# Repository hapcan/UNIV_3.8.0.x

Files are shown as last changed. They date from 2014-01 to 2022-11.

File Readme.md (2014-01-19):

UNIV 3.8.0.x
============

RGB LED Controller - 3 channel LED or 1 channel RGB LED controller 5A per channel @12-24V for DIN rail

Device webpage: http://hapcan.com/devices/universal/univ_3/univ_3-8-0-x/

Hardware created in Eagle PCB Software http://www.cadsoftusa.com/

Firmware created in Microchip MPLAB http://www.microchip.com/mplabide/ in assembly language

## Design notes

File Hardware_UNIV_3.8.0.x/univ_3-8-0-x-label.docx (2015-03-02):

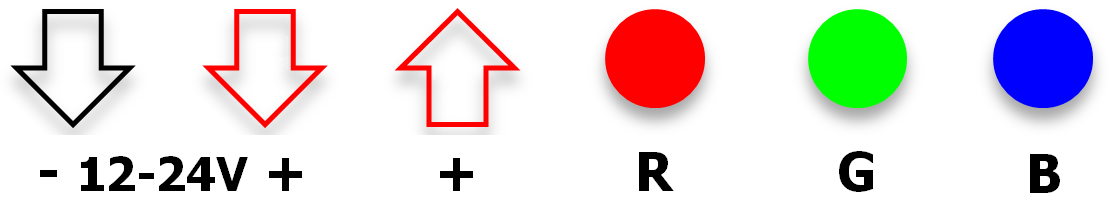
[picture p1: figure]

RGB LED

CONTROLLER

IN = 3x5A UN = 12-24V
TYPE | UNIV 3.8.0.x
S/N | 000005D8h

hapcan.com

STEROWNIK

RGB LED

IN = 3x5A UN = 12-24V
TYP | UNIV 3.8.0.x
S/N | 000005D8h

hapcan.com

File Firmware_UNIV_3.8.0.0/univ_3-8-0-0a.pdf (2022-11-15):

# RGB LED CONTROLLER FIRMWARE

# UNIV 3.8.0.0

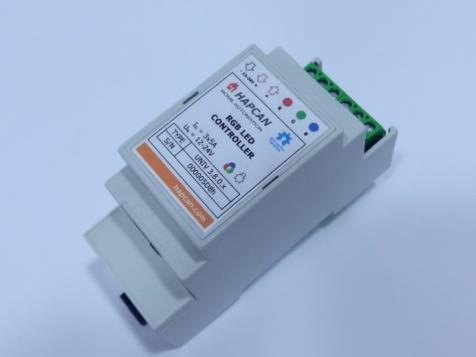
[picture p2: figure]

© 2014 hapcan.com | univ_3-8-0-0a.pdf - page 1 / 6

## 1. Features

- Firmware for RGB LED controller - Voltage control (PWM) in 255 steps (0-255) for each channel - MASTER channel adjustable in 255 steps as well - Possibility to set up minimum and maximum value for each channel - Last state memory - Adjustable dimming time for each channel - 37 control instructions - 3 blocking instructions - 4 timers (1 for each channel) for instruction execution delay 1s-24h - Allows defining up to 128 CAN messages which can indirectly control the module - Settable power up states - Uptime counter - Health check monitor - Transmit (42 messages) and receive (42 messages) FIFO buffers

## 2. Compatibility - Firmware for UNIV 3.8.0.x module - Firmware can be uploaded into processor with bootloader version 3.1 or

compatible.

## 3. Firmware version

UNIV | 3 | . | 8 | . | 0 | . | 0

## firmware version application version application type (RGB LED controller) processor version universal processor

## 4. Communication Frames (messages)

## 4.1. RGB LED controller message

The module sends message to the bus, when the status of any channel changes.

## Table 1. RGB LED controller frame (0x308)

Frame type | Flags | Module | Group | D0 | D1 | D2 | D3 | D4 | D5 | D6 | D7
0x308 | 3 | 2 | 1 | 0 | Node Nr | Group Nr | 0xFF | 0xFF | CHANNEL | STATUS | RELAY | INSTR1 | INSTR2 | TIMER
0x308 | – universal module frame, RGB LED controller
3 | - | - not used flag, read as “0”
2 | - | - not used flag, read as “0”
1 | - | - not used flag, read as “0”
0 | RE | - response flag, flag is equal “1” if node was requested. If flag is equal „0” it means that status of output has just changed.
Node Nr | - message sender node number
Group Nr | - message sender group number
CHANNEL | - output channel (0x01 – red, 0x02 – green, 0x03 – blue, 0x04 - MASTER)
STATUS | - current status of output 0x00 – 0xFF
PRZEK | - current status of all channels (0x00 – if all channels are turned off, 0xFF – if master
| | channel and any colour channe is on) – this byte can be used to toggle relay which
| | turns on the power supply for the LED. This byte is only available in MASTER channel frame
INSTR1 | - instruction that is waiting for execution, or 0xFF if none instruction
INSTR2 | - second byte of instruction that is waiting for execution, or 0xFF
TIMER | - delay value of waiting instruction, or 0x00 if none waiting

# UNIV 3.8.0.0

## 4.2. Status request

Status of module can be checked by sending from computer STATUS REQUEST frame (0x109) (Table 2).

Table 2. STATUS REQUEST frame (0x109).
Frame type | Flags | Module | Group | D0 | D1 | D2 | D3 | D4 | D5 | D6 | D7
0x109 | 0x0 | COMP ID1 | COMP ID2 | 0xXX | 0xXX | Node Nr | Group Nr | 0xXX | 0xXX | 0xXX | 0xXX
0x1090 | – STATUS REQUEST frame
COMP ID1 | - computer identifier (must be unique on the network)
COMP ID2 | - computer identifier (must be unique on the network)
Node Nr | - node number of requested module
Group Nr | - group number of requested module
0xXX | - inessential data

As response the module will send RGB LED frames. The meaning of bytes is the same as in Table 1.

## Table 3. Response to STATUS REQUEST

Frame type | Flags | Module | Group | D0 | D1 | D2 | D3 | D4 | D5 | D6 | D7
0x308 | 0x1 | Node Nr | Group Nr | 0xFF | 0xFF | 0x01 | STATUS | 0xFF | INSTR1 | INSTR2 | TIMER1
Frame type | Flags | Module | Group | D0 | D1 | D2 | D3 | D4 | D5 | D6 | D7
0x308 | 0x1 | Node Nr | Group Nr | 0xFF | 0xFF | 0x02 | STATUS | 0xFF | INSTR1 | INSTR2 | TIMER2
Frame type | Flags | Module | Group | D0 | D1 | D2 | D3 | D4 | D5 | D6 | D7
0x308 | 0x1 | Node Nr | Group Nr | 0xFF | 0xFF | 0x03 | STATUS | 0xFF | INSTR1 | INSTR2 | TIMER3
Frame type | Flags | Module | Group | D0 | D1 | D2 | D3 | D4 | D5 | D6 | D7
0x308 | 0x1 | Node Nr | Group Nr | 0xFF | 0xFF | 0x04 | STATUS | RELAY | INSTR1 | INSTR2 | TIMER4

## 4.3. Uptime request

Table 4. UPTIME REQUEST (0x113).
Frame type | Flags | Module | Group | D0 | D1 | D2 | D3 | D4 | D5 | D6 | D7
0x113 | 0x0 | COMP ID1 | COMP ID2 | 0xXX | 0xXX | Node Nr | Group Nr | 0xXX | 0xXX | 0xXX | 0xXX
0x1130 | – UPTIME REQUEST frame
COMP ID1 | - computer identifier (must be unique on the network)
COMP ID2 | - computer identifier (must be unique on the network)
Node Nr | - node number of requested module
Group Nr | - group number of requested module
0xXX | - inessential data

Table 5. Response to UPTIME REQUEST (0x113).
Frame type | Flags | Module | Group | D0 | D1 | D2 | D3 | D4 | D5 | D6 | D7
0x113 | 0x1 | Node Nr | Group Nr | 0xFF | 0xFF | 0xFF | 0xFF | UPTIME3 | UPTIME2 | UPTIME1 | UPTIME0
0x1131 | – Response to UPTIME REQUEST frame
Node Nr | - node number on the network
Group Nr | - group number of the node on the network
UPTIME | - (UPTIME3*256³+UPTIME2*256²+UPTIME1*256¹+UPTIME3*256⁰

### ) in seconds

## 4.4. Health check request

Table 6. HEALTH CHECK - STATUS REQUEST (0x115).
Frame type | Flags | Module | Group | D0 | D1 | D2 | D3 | D4 | D5 | D6 | D7
0x115 | 0x0 | COMP ID1 | COMP ID2 | 0x01 | 0xXX | Node Nr | Group Nr | 0xXX | 0xXX | 0xXX | 0xXX
0x1150 | – HEALTH CHECK REQUEST frame
COMP ID1 | - computer identifier (must be unique on the network)
COMP ID2 | - computer identifier (must be unique on the network)
0x01 | - status request
Node Nr | - node number of requested module
Group Nr | - group number of requested module
0xXX | - inessential data

As response the module will send two frames (Table 7).

Table 7. Response to HEALTH CHECK - STATUS REQUEST (0x115).
Frame type | Flags | Module | Group | D0 | D1 | D2 | D3 | D4 | D5 | D6 | D7
0x115 | 0x1 | Node Nr | Group Nr | 0x01 | RXCNT | TXCNT | RXCNTMX | TXCNTMX | CANINTCNT | RXERRCNT | TXERRCNT
0x1151 | – Response to HEALTH CHECK REQUEST frame
Node Nr | - node number on the network
Group Nr | - group number of the node on the network
0x01 | - frame 1 (current values)
RXCNT | - current level of receive FIFO buffer
TXCNT | - current level of transmit FIFO buffer
RXCNTMX | - maximum level of receive FIFO buffer since power up
TXCNTMX | - maximum level of transmit FIFO buffer since power up
CANINTCNT | - number of CAN interface restarts since power up
RXERRCNT | - current receive errors register
TXERRCNT | - current transmit errors register
Frame type | Flags | Module | Group | D0 | D1 | D2 | D3 | D4 | D5 | D6 | D7
0x115 | 0x1 | Node Nr | Group Nr | 0x02 | 0xFF | 0xFF | RXCNTMXE | TXCNTMXE | CANINTCNTE | RXERRCNTE | TXERRCNTE
0x1151 | – Response to HEALTH CHECK REQUEST frame
Node Nr | - node number on the network
Group Nr | - group number of the node on the network
0x02 | - frame 2 (maximum values saved in eeprom memory)
RXCNTMXE | - maximum ever level of receive FIFO buffer
TXCNTMXE | - maximum ever level of transmit FIFO buffer
CANINTCNTE | - maximum ever number of CAN interface restarts
RXERRCNTE | - maximum ever receive errors
TXERRCNTE | - maximum ever transmit errors

To clear maximum values saved in eeprom memory the frame shown in Table 8 must be sent. There is no response to this message.

Table 8. HEALTH CHECK - CLEAR REQUEST (0x115).
Frame type | Flags | Module | Group | D0 | D1 | D2 | D3 | D4 | D5 | D6 | D7
0x115 | 0x0 | COMP ID1 | COMP ID2 | 0x02 | 0xXX | Node Nr | Group Nr | 0xXX | 0xXX | 0xXX | 0xXX
0x1150 | – HEALTH CHECK REQUEST frame
COMP ID1 | - computer identifier (must be unique on the network)
COMP ID2 | - computer identifier (must be unique on the network)
0x02 | - clear request
Node Nr | - node number of requested module
Group Nr | - group number of requested module
0xXX | - inessential data

## 5. Module control

The module can be controlled directly from PC, or indirectly by other modules.

## 5.1. Control instruction

The table below shows all instructions, which can be executed by the module. Some of them can be executed only with direct control and other with indirect control (through other modules).

## Table 9. Module control instructions

Instrukcja | Instruction Codding | Note | Control
INSTR1 | INSTR2 | INSTR3 | INSTR4 | INSTR5 | INSTR6 | INSTR7 | INSTR8
SET LED1 (R) TO… | 0x00 | STATE | TIMER | 0xXX | 0xXX | 0xXX | 0xXX | 0xXX | Sets the state of the channel immediately at the level specified by the byte STATE (0-255). Instructions may be delayed if the TIMER is not zero. | √ | √
SET LED2 (G) TO… | 0x01 | STATE | TIMER | 0xXX | 0xXX | 0xXX | 0xXX | 0xXX
SET LED3 (B) TO… | 0x02 | STATE | TIMER | 0xXX | 0xXX | 0xXX | 0xXX | 0xXX
SET MASTER TO… | 0x03 | STATE | TIMER | 0xXX | 0xXX | 0xXX | 0xXX | 0xXX
TOGGLE LED1 | 0x04 | 0xXX | TIMER | 0xXX | 0xXX | 0xXX | 0xXX | 0xXX | If the channel is on, it will be turned off. If it is off, it will be turned to the maximum or the last memorized value (if state memory is set in the configuration). Instructions may be delayed if the TIMER is not zero. | √ | √
TOGGLE LED2 | 0x05 | 0xXX | TIMER | 0xXX | 0xXX | 0xXX | 0xXX | 0xXX
TOGGLE LED3 | 0x06 | 0xXX | TIMER | 0xXX | 0xXX | 0xXX | 0xXX | 0xXX
TOGGLE MASTER | 0x07 | 0xXX | TIMER | 0xXX | 0xXX | 0xXX | 0xXX | 0xXX
STEP DOWN LED1 BY … | 0x08 | VALUE | TIMER | 0xXX | 0xXX | 0xXX | 0xXX | 0xXX | Channel state will be reduced by the value indicated in the VALUE byte. | √ | √
STEP DOWN LED2 BY … | 0x09 | VALUE | TIMER | 0xXX | 0xXX | 0xXX | 0xXX | 0xXX
STEP DOWN LED3 BY … | 0x0A | VALUE | TIMER | 0xXX | 0xXX | 0xXX | 0xXX | 0xXX
STEP DOWN MASTER BY … | 0x0B | VALUE | TIMER | 0xXX | 0xXX | 0xXX | 0xXX | 0xXX
STEP UP LED1 BY … | 0x0C | VALUE | TIMER | 0xXX | 0xXX | 0xXX | 0xXX | 0xXX | Channel state will be increased by the value indicated in the VALUE byte. | √ | √
STEP UP LED2 BY … | 0x0D | VALUE | TIMER | 0xXX | 0xXX | 0xXX | 0xXX | 0xXX
STEP UP LED3 BY … | 0x0E | VALUE | TIMER | 0xXX | 0xXX | 0xXX | 0xXX | 0xXX
STEP UP MASTER BY … | 0x0F | VALUE | TIMER | 0xXX | 0xXX | 0xXX | 0xXX | 0xXX
SET LED1 (R) SOFTLY TO… | 0x10 | STATE | TIMER | 0xXX | 0xXX | 0xXX | 0xXX | 0xXX | Sets the state of the channel slowly to the level specified by the byte STATE (0-255). Instructions may be delayed if the TIMER is not zero. | √ | √
SET LED2 (G) SOFTLY TO… | 0x11 | STATE | TIMER | 0xXX | 0xXX | 0xXX | 0xXX | 0xXX
SET LED3 (B) SOFTLY TO… | 0x12 | STATE | TIMER | 0xXX | 0xXX | 0xXX | 0xXX | 0xXX
SET MASTER SOFTLY TO… | 0x13 | STATE | TIMER | 0xXX | 0xXX | 0xXX | 0xXX | 0xXX
STOP LED1 | 0x14 | 0xXX | 0xXX | 0xXX | 0xXX | 0xXX | 0xXX | 0xXX | It stops instruction which is being executed eg. START or SET SOFTLY TO ... | √ | √
STOP LED2 | 0x15 | 0xXX | 0xXX | 0xXX | 0xXX | 0xXX | 0xXX | 0xXX
STOP LED3 | 0x16 | 0xXX | 0xXX | 0xXX | 0xXX | 0xXX | 0xXX | 0xXX
STOP MASTER | 0x17 | 0xXX | 0xXX | 0xXX | 0xXX | 0xXX | 0xXX | 0xXX
START LED1 | 0x18 | 0xXX | 0xXX | 0xXX | 0xXX | 0xXX | 0xXX | 0xXX | Instruction START begins typical control process. If within 400ms from START instruction, controller receives STOP instruction then it toggles channel’s state (exactly the same as TOGGLE instruction). If after that time instruction STOP is not received then channel is brightened (if previous state was min or 0), or channel is dimmed (if previous state was max). It gives possibility to control with one button. If button is pressed for less than 400ms the channel will turn on or off. If button is pressed for longer than 400ms, then channel will dim or brighten. | √ | √
START LED2 | 0x19 | 0xXX | 0xXX | 0xXX | 0xXX | 0xXX | 0xXX | 0xXX
START LED3 | 0x1A | 0xXX | 0xXX | 0xXX | 0xXX | 0xXX | 0xXX | 0xXX
START MASTER | 0x1B | 0xXX | 0xXX | 0xXX | 0xXX | 0xXX | 0xXX | 0xXX
SET LED1 SPEED TO … | 0x1C | VALUE | 0xXX | 0xXX | 0xXX | 0xXX | 0xXX | 0xXX | It sets dimming time of particular channel. VALUE byte (0-255) defines time when channel changes its state from 0 to 255. This byte can hold value from 0 – 255 which corresponds to 1s – 256s. | √ | √
SET LED2 SPEED TO … | 0x1D | VALUE | 0xXX | 0xXX | 0xXX | 0xXX | 0xXX | 0xXX
SET LED3 SPEED TO … | 0x1E | VALUE | 0xXX | 0xXX | 0xXX | 0xXX | 0xXX | 0xXX
SET MASTER SPEED TO … | 0x1F | VALUE | 0xXX | 0xXX | 0xXX | 0xXX | 0xXX | 0xXX
SET RGB TO… | 0x20 | STATE1 | STATE2 | STATE3 | TIMER | 0xXX | 0xXX | 0xXX | It sets immediately values of three colour channels. Instruction may be delayed if the TIMER is not zero. | √ | √
SET SOFTLY RGB TO… | 0x21 | STATE1 | STATE2 | STATE3 | TIMER | 0xXX | 0xXX | 0xXX | It sets slowly values of three colour channels. Instruction may be delayed if the TIMER is not zero. | √ | √
SET RGB SPEED TO… | 0x22 | VALUE | 0xXX | 0xXX | 0xXX | 0xXX | 0xXX | 0xXX | It sets dimming time of three colour channels. VALUE byte (0-255) defines time when channel changes its state from 0 to 255. This byte can hold value from 0 – 255 which corresponds to 1s – 256s. | √ | √
RGB SPEED UP | 0x23 | 0xXX | 0xXX | 0xXX | 0xXX | 0xXX | 0xXX | 0xXX | It changes dimming speed of three colour channels to next lower value | √ | √
RGB SPEED DOWN | 0x24 | 0xXX | 0xXX | 0xXX | 0xXX | 0xXX | 0xXX | 0xXX | It changes dimming speed of three colour channels to next higher value | √ | √
PROGRAM | 0x25 | 0x00 | 0xXX | 0xXX | 0xXX | 0xXX | 0xXX | 0xXX | It stops any running program. | √ | √
| | 0x01 | 0xXX | 0xXX | 0xXX | 0xXX | 0xXX | 0xXX | Program 1 – every program calling causes colour changing with sequence: 1-red 2-green 3-blue 4-yellow 5-cyan 6-violet 7-white
| | 0x02 | 0xXX | 0xXX | 0xXX | 0xXX | 0xXX | 0xXX | Program 2 – first program calling runs automatic colour changing with current dimming speed beginning from red colour. The second program calling stops colour. Another calling starts colour changing with reversed order.
ENABLE BOX | 0xDD | BoxX | BoxY | 0xXX | 0xXX | 0xXX | 0xXX | 0xXX | It enables chosen boxes – these boxes will be compared with next received message from the bus. | | √
DISABLE BOX | 0xDE | BoxX | BoxY | 0xXX | 0xXX | 0xXX | 0xXX | 0xXX | It disables chosen boxes – these boxes will be passed when next message arrives from the bus. | | √
TOGGLE BOX | 0xDF | BoxX | BoxY | 0xXX | 0xXX | 0xXX | 0xXX | 0xXX | It toggles boxes – enables when they are disabled and vice versa | | √

Direct

Indirect

0xXX – inessential data

BoxX | Note
0x00 | - from Box 1
0x01 | - from Box 2
…
0x7F | - from Box 128
BoxY | Note
0x00 | + 0 -(and not anyone else)
0x01 | + 1 -( and 1 following)
…
0x7F | +127 -( and 127 following)

## 5.2. Timer

Each channel has its own timer which can delay execution of the instruction. Delay can be chosen between 1s-24h set in TIMER register. Drawing below shows delay dependence of TIMER register.

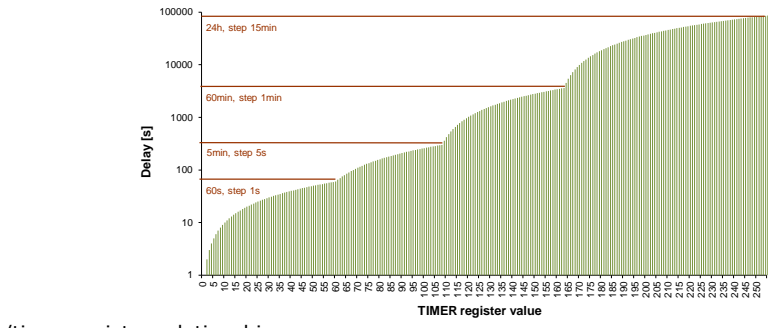
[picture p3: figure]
Delay [s]; TIMER register value; 60s, step 1s; 5min, step 5s; 60min, step 1min; 24h, step 15min

## Figure 1. Delay/timer register relationship

## 5.3. Direct control

It is possible to control module by sending DIRECT CONTROL message. The message contains instruction, which will be executed by the module.

Table 10. DIRECT CONTROL frame (0x10A).
Frame type | Flags | Module | Group | D0 | D1 | D2 | D3 | D4 | D5 | D6 | D7
0x10A | 0x0 | COMP ID1 | COMP ID2 | INSTR1 | INSTR2 | Node Nr | Group Nr | INSTR3 | INSTR4 | INSTR5 | INSTR6
0x10A | – DIRECT CONTROL frame
COMP ID1 | - computer identifier (must be unique on the network)
COMP ID2 | - computer identifier (must be unique on the network)
Node Nr | - node number of requested module
Group Nr | - group number of requested module
INSTR1-6 | - instruction to be executed (byte1)

## 5.4. Indirect control

Indirect control means that module will react to messages sent by other modules on the network. It depends on configuration programmed into the module boxes (memory cells).
This firmware has feature to set simple conditions of executing instruction. To do so, you can use blocking instruction (0xDD – 0xDF) shown in Table 9.

## 6. Configuration Parameters that can be configured with this firmware:

- Module identifier (module number and group number);
- Module description (16 chars);
- Minimum and maximum values;
- Power up dimming speed;
- Power up states;
- Last state memory;
- Text notes;
- Linking device with other modules (indirect control of module). Configuration process can be done using HAPCAN Programmer.

## 6.1. Module identifier

Every module on the network must have unique identifier. The identifier is made of two bytes, module number (1 byte) and group number (1 byte). Identifier of the Ethernet Interface can be changed in HAPCAN Programmer in software settings.

## 6.2. Module description

Every module can have 16 char description, which makes easier for user (programmer) to distinguish nodes.

## 6.3. Minimum and maximum values

It is possible to set minimum and maximum values for each channel.

## 6.4. Power up dimming speed

This parameter defines how fast channel goes from value 0 to value 255. The dimming speed can be chosen between 1s and 256s with 1s step.

## 6.5. Power up states

It is possible to configure channel states at startup after power loss. At startup values can be chosen between 0 and 255 or the or the last state saved in non-volatile memory can be taken. The last state value must be unchanged for at least 6s before power failure.

## 6.6. Last state memory

The last state of any channel can be remembered. In this mode, when channel is being switched on, it sets to the value that was before switching off. In no state memory mode it sets to the maximum value.

6.7. Text notes.
Up to 1024 characters can be written into processor’s memory.

## 6.8. Linking devices

The module has 128 memory cells (boxes). Each box can contain information about message sent by other node, and instruction which will be executed when that message is received.

## 7. License

## HAPCAN Home Automation Project firmware, Copyright (C) 2014 hapcan.com

This program is free firmware: you can redistribute it and/or modify it under the terms of the GNU General Public License as published by the Free Software Foundation, either version 3 of the License, or (at your option) any later version.

This firmware is distributed in the hope that it will be useful, but WITHOUT ANY WARRANTY; without

## even the implied warranty of MERCHANTABILITY or FITNESS FOR A PARTICULAR PURPOSE. See the

GNU General Public License for more details.

You should have received a copy of the GNU General Public License along with this firmware. If not, see http://www.gnu.org/licenses/gpl-3.0.html.

## 8. Document version

File | Note | Date
univ_3-8-0-0a.pdf | Original version | January 2014

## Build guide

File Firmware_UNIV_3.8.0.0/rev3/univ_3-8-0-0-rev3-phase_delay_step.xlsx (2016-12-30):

TIME reg | number of 20ms interrupts | number of steps on each 20ms | calculated PHASE step value (HEX) |  |  | final real PHASE delay
0 | 50 | 5.1 | 51999 | 334233 | 5.100068666 | 0.9999865363
1 | 100 | 2.55 | 28CCC | 167116 | 2.550026703 | 1.999979056
2 | 150 | 1.7 | 1B333 | 111411 | 1.700022889 | 2.999959609
3 | 200 | 1.275 | 14666 | 83558 | 1.275013352 | 3.999958113
4 | 250 | 1.02 | 1051E | 66846 | 1.020004578 | 4.99997756
5 | 300 | 0.85 | D999 | 55705 | 0.8500038148 | 5.999973072
6 | 350 | 0.7285714286 | BA83 | 47747 | 0.7285725185 | 6.999989528
7 | 400 | 0.6375 | A333 | 41779 | 0.6375066758 | 7.999916226
8 | 450 | 0.5666666667 | 9111 | 37137 | 0.5666742962 | 8.999878827
9 | 500 | 0.51 | 828F | 33423 | 0.5100022889 | 9.999955121
10 | 550 | 0.4636363636 | 76B0 | 30384 | 0.4636301213 | 11.0001481
11 | 600 | 0.425 | 6CCC | 27852 | 0.4249942779 | 12.00016157
12 | 650 | 0.3923076923 | 646E | 25710 | 0.392309453 | 12.99994166
13 | 700 | 0.3642857143 | 5D41 | 23873 | 0.3642786297 | 14.00027227
14 | 750 | 0.34 | 570A | 22282 | 0.3400015259 | 14.99993268
15 | 800 | 0.31875 | 5199 | 20889 | 0.3187457084 | 16.00021542
16 | 850 | 0.3 | 4CCC | 19660 | 0.2999923705 | 17.00043235
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

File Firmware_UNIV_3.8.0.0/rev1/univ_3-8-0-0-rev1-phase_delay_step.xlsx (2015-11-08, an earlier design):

TIME reg | number of 20ms interrupts | number of stapes on each 20ms | calculated PHASE step value (HEX) |  |  | final real PHASE delay
0 | 50 | 5.1 | 51999 | 334233 | 5.100068666 | 0.9999865363
1 | 100 | 2.55 | 28CCC | 167116 | 2.550026703 | 1.999979056
2 | 150 | 1.7 | 1B333 | 111411 | 1.700022889 | 2.999959609
3 | 200 | 1.275 | 14666 | 83558 | 1.275013352 | 3.999958113
4 | 250 | 1.02 | 1051E | 66846 | 1.020004578 | 4.99997756
5 | 300 | 0.85 | D999 | 55705 | 0.8500038148 | 5.999973072
6 | 350 | 0.7285714286 | BA83 | 47747 | 0.7285725185 | 6.999989528
7 | 400 | 0.6375 | A333 | 41779 | 0.6375066758 | 7.999916226
8 | 450 | 0.5666666667 | 9111 | 37137 | 0.5666742962 | 8.999878827
9 | 500 | 0.51 | 828F | 33423 | 0.5100022889 | 9.999955121
10 | 550 | 0.4636363636 | 76B0 | 30384 | 0.4636301213 | 11.0001481
11 | 600 | 0.425 | 6CCC | 27852 | 0.4249942779 | 12.00016157
12 | 650 | 0.3923076923 | 646E | 25710 | 0.392309453 | 12.99994166
13 | 700 | 0.3642857143 | 5D41 | 23873 | 0.3642786297 | 14.00027227
14 | 750 | 0.34 | 570A | 22282 | 0.3400015259 | 14.99993268
15 | 800 | 0.31875 | 5199 | 20889 | 0.3187457084 | 16.00021542
16 | 850 | 0.3 | 4CCC | 19660 | 0.2999923705 | 17.00043235
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

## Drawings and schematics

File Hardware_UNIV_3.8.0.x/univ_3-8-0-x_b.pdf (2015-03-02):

## RGB LED CONTROLLER

# UNIV 3.8.0.x

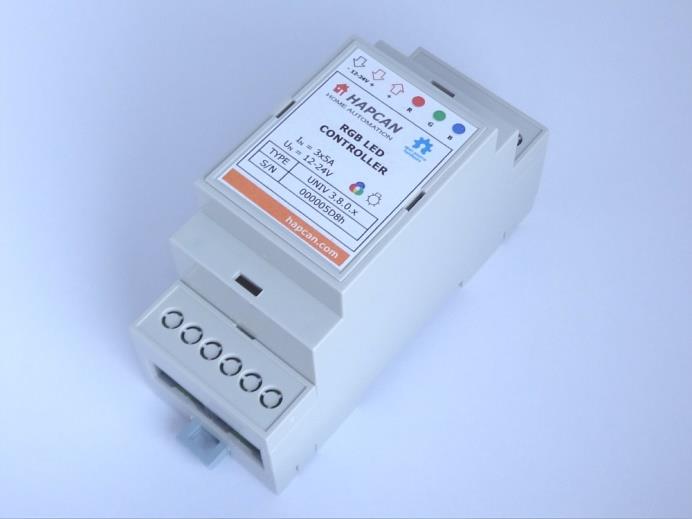
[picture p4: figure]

© 2014 hapcan.com | univ_3-8-0-x_b.pdf - page 1 / 6

### 1. Features

- 3 channel LED controller
- Maximum load 120VA for each channel
- PWM (Pulse Width Modulation)
- Controller can generate any colour with required intensity of common anode RGB LED.
- Can work with:
- - RGB LEDs or three single colour LEDs (eg. LED strips, tapes, tubes etc.)
- - low voltage bulbs (classical and halogen 12-24V)
- Maximum LED supply voltage 12-24V
- Maximum LED current 5A for each channel
- Operation voltage 10-24V.
- Maximum current consumption from the bus 26mA.
- For DIN rail mounting.
- Dimensions 90x58x36 mm (2 mod)
- Operating of module depends on firmware uploaded into it.
- Schematic and PCB design can be downloaded from hapcan.com site

### 2. Application version

UNIV | 3 | . | 8 | . | 0 | . | x
firmware version
application version
application type (RGB LED controller) processor version
universal processor

### 3. Technical data

Bus side
Parameter | Symbol | Value | Unit
Power supply voltage | US | 10-24V | V
Maximum current consumption with all channels turn on | ISMAX | 26 | mA
Bus quiescent current | ISQ | 7 | mA
Bus connector type | 2x RJ45 connectors

RGB LED side
Parameter | Symbol | Value | Unit
Power supply voltage | UN | 12-24V | V
Maximum LED current for one channel | IN | 5 | A
Load Power for one channel | SN | 120 | VA
Voltage regulating range | Uφ | 0 - UN | V
PWM frequency | f | 488 | Hz
Connector type | Terminal block 4mm²

## UNIV 3.8.0.x

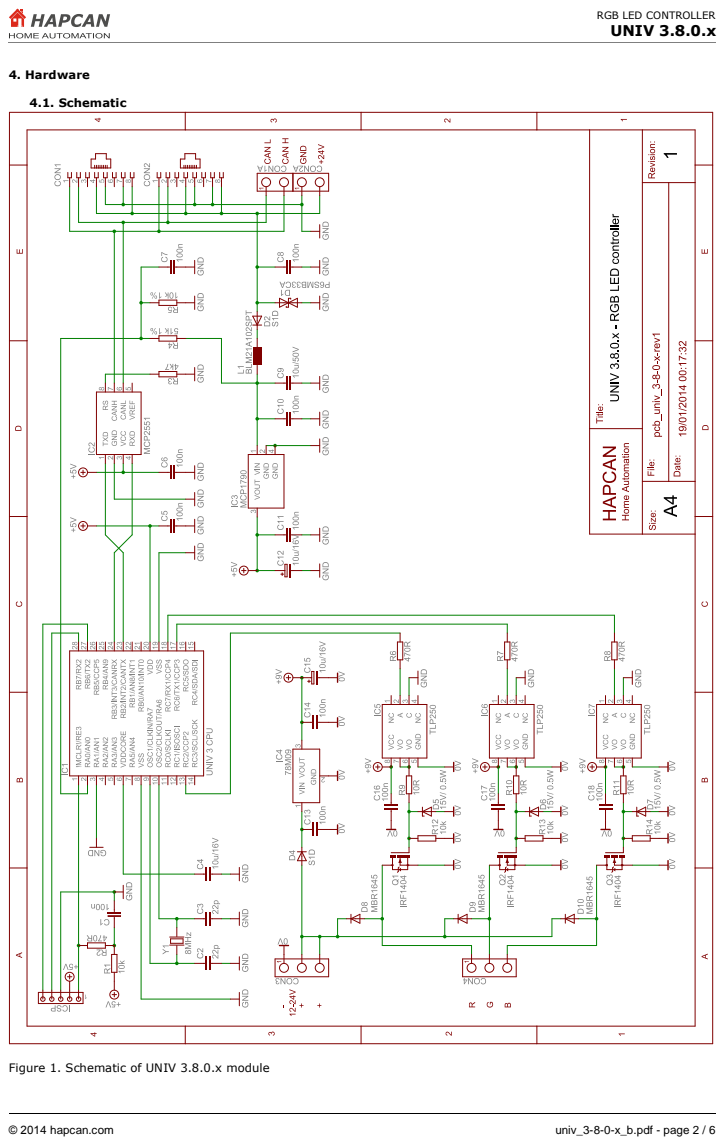
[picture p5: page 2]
4. Hardware; 4.1. Schematic

Figure 1. Schematic of UNIV 3.8.0.x module

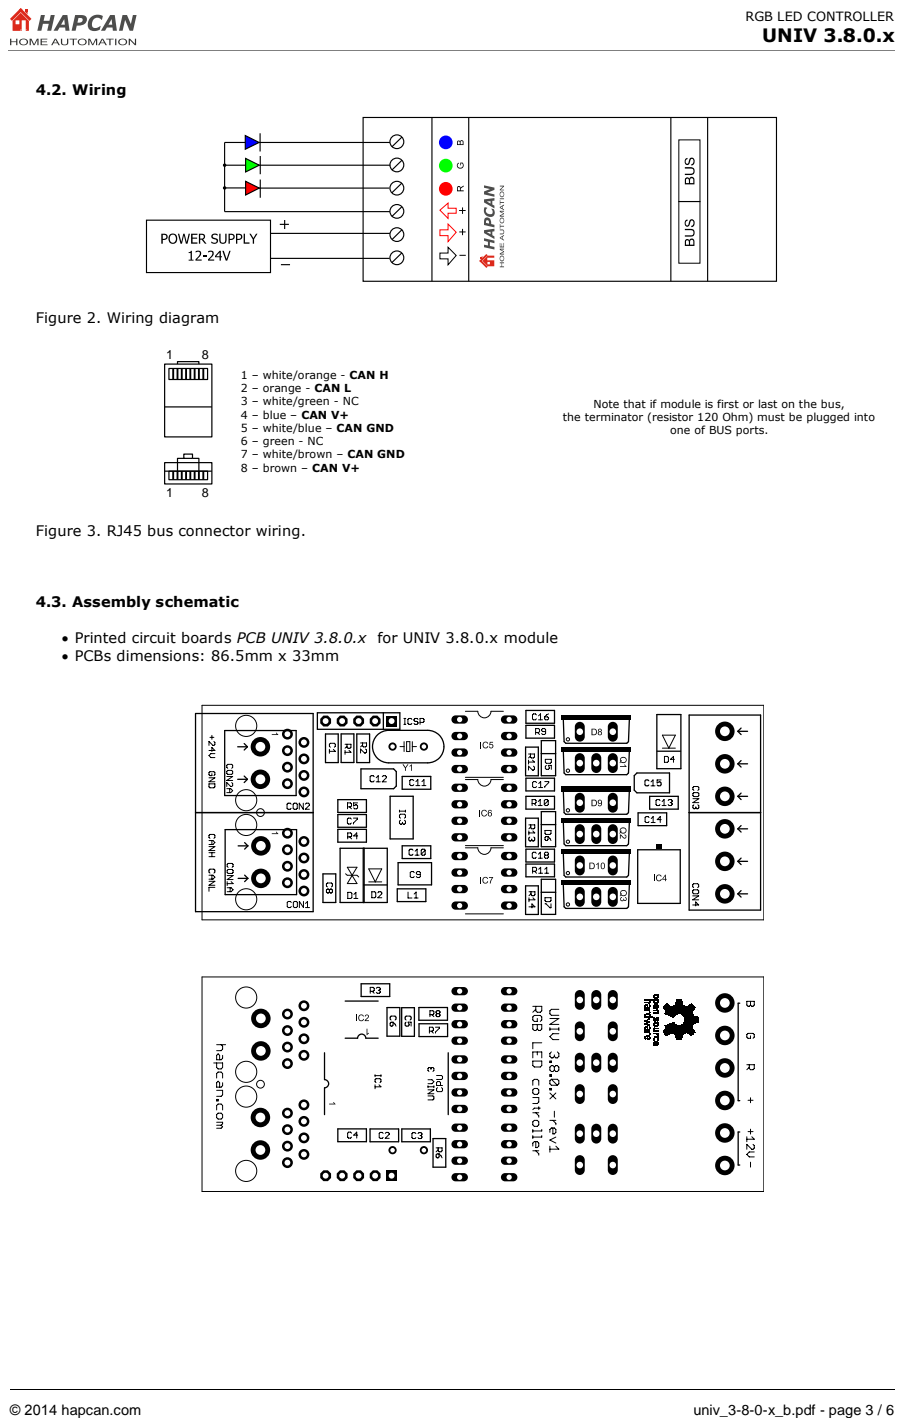
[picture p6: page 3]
4.2. Wiring; 4.3. Assembly schematic

Figure 2. Wiring diagram

1 – white/orange - CAN H
2 – orange - CAN L
3 – white/green - NC
4 – blue – CAN V+
5 – white/blue – CAN GND
6 – green - NC
7 – white/brown – CAN GND
8 – brown – CAN V+

Note that if module is first or last on the bus,
the terminator (resistor 120 Ohm) must be plugged into

one of BUS ports.

Figure 3. RJ45 bus connector wiring.

• Printed circuit boards PCB UNIV 3.8.0.x for UNIV 3.8.0.x module
• PCBs dimensions: 86.5mm x 33mm

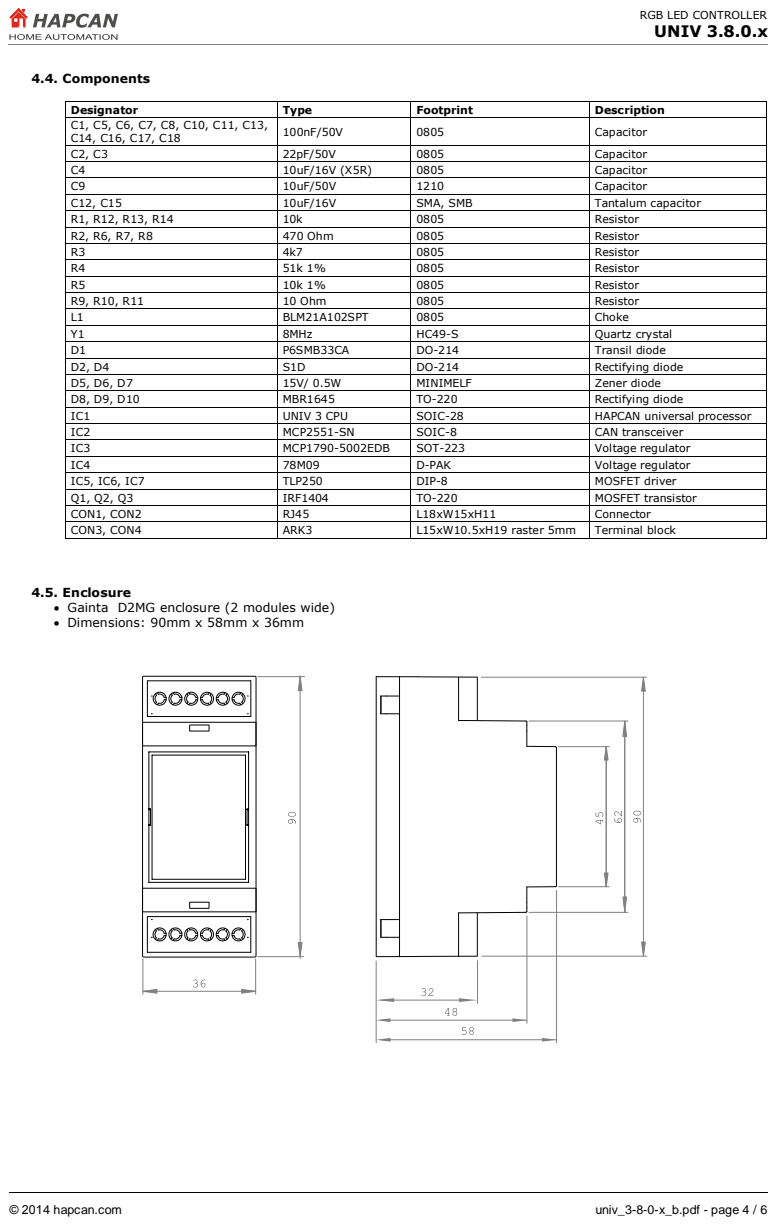
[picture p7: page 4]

Designator | Type | Footprint | Description
C1, C5, C6, C7, C8, C10, C11, C13, C14, C16, C17, C18 | 100nF/50V | 0805 | Capacitor

C2, C3 | 22pF/50V | 0805 | Capacitor
C4 | 10uF/16V (X5R) | 0805 | Capacitor
C9 | 10uF/50V | 1210 | Capacitor
C12, C15 | 10uF/16V | SMA, SMB | Tantalum capacitor
R1, R12, R13, R14 | 10k | 0805 | Resistor
R2, R6, R7, R8 | 470 Ohm | 0805 | Resistor
R3 | 4k7 | 0805 | Resistor
R4 | 51k 1% | 0805 | Resistor
R5 | 10k 1% | 0805 | Resistor
R9, R10, R11 | 10 Ohm | 0805 | Resistor
L1 | BLM21A102SPT | 0805 | Choke
Y1 | 8MHz | HC49-S | Quartz crystal
D1 | P6SMB33CA | DO-214 | Transil diode
D2, D4 | S1D | DO-214 | Rectifying diode
D5, D6, D7 | 15V/ 0.5W | MINIMELF | Zener diode
D8, D9, D10 | MBR1645 | TO-220 | Rectifying diode
IC1 | UNIV 3 CPU | SOIC-28 | HAPCAN universal processor
IC2 | MCP2551-SN | SOIC-8 | CAN transceiver
IC3 | MCP1790-5002EDB | SOT-223 | Voltage regulator
IC4 | 78M09 | D-PAK | Voltage regulator
IC5, IC6, IC7 | TLP250 | DIP-8 | MOSFET driver
Q1, Q2, Q3 | IRF1404 | TO-220 | MOSFET transistor
CON1, CON2 | RJ45 | L18xW15xH11 | Connector
CON3, CON4 | ARK3 | L15xW10.5xH19 raster 5mm | Terminal block

4.5. Enclosure
• Gainta D2MG enclosure (2 modules wide)
• Dimensions: 90mm x 58mm x 36mm

### 4.7. Mechanical processing

Striped parts must be removed.

BODY | TERMINAL GUARDS

### 4.8. Labels

Editable labels version is available on hapcan.com site.

### 5. Commissioning

### 5.1. CPU voltage measurement

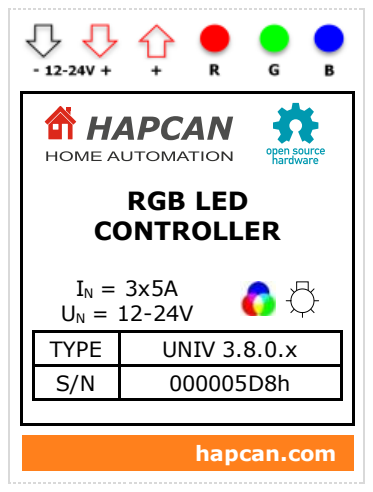
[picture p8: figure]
RGB LED CONTROLLER; TYPE; UNIV 3.8.0.x; hapcan.com

After verifying the correctness and quality of the soldering, the bus voltage should be connected while measuring the processor voltage. To do this, connect a voltmeter to pins 2 and 3 of the ICSP connector. Processor supply voltage should be about 5V.

Figure 3. CPU voltage measurement

### 5.2. Checking the CPU clock

Proper operation of the CPU can be checked by temporarily connecting the LED to pins 3 and 5 of the ICSP connector. When device is powered, the LED should light up four times in the sequence 1 second on - 1 second off
- 1 second on. The LED lights up only once for 50ms, if the processor is in programming mode.

Figure 4. Checking the CPU clock
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

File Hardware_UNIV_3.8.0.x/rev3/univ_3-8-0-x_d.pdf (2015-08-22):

## RGB LED CONTROLLER

# UNIV 3.8.0.x


© 2015 hapcan.com | univ_3-8-0-x_d.pdf - page 1 / 6

### 1. Features

- 3 channel LED controller
- Maximum load 360W (120W for each channel)
- PWM (Pulse Width Modulation)
- Controller can generate any colour with required intensity of common anode RGB LED.
- Can work with:
- - RGB LEDs or three single colour LEDs (eg. LED strips, tapes, tubes etc.)
- - low voltage bulbs (classical and halogen 12-24V)
- Maximum LED supply voltage 12-24V
- Maximum LED current 5A for each channel
- Operation voltage from the bus 10-24V.
- Maximum current consumption from the bus 26mA.
- For DIN rail mounting.
- Dimensions 90x58x36 mm (2 mod)
- Functionality of the device depends on the installed firmware.
- Schematic and PCB design can be downloaded from hapcan.com site

### 2. Application version

UNIV | 3 | . | 8 | . | 0 | . | x
firmware version
application version
application type (RGB LED controller) processor version
universal processor

### 3. Technical data

Bus side
Parameter | Symbol | Value | Unit
Power supply voltage | US | 10-24V | V
Maximum current consumption with all channels turn on | ISMAX | 26 | mA
Bus quiescent current | ISQ | 7 | mA
Bus connector type | 2x RJ45 connectors

RGB LED side
Parameter | Symbol | Value | Unit
Power supply voltage | UN | 12-24V | V
Maximum LED current for one channel | IN | 5 | A
Load Power for one channel | SN | 120 @24V | W
Voltage regulating range | Uφ | 0 - UN | V
PWM frequency | f | 488 | Hz
Connector type | Terminal block 4mm²

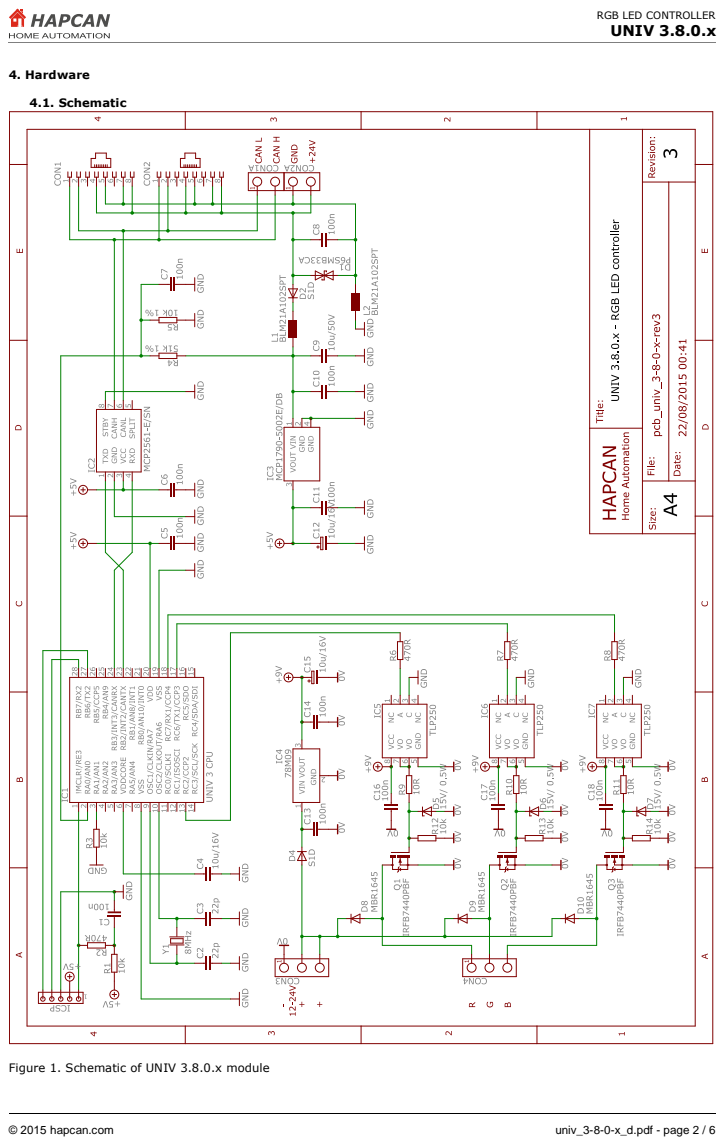
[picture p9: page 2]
4. Hardware; 4.1. Schematic

Figure 1. Schematic of UNIV 3.8.0.x module

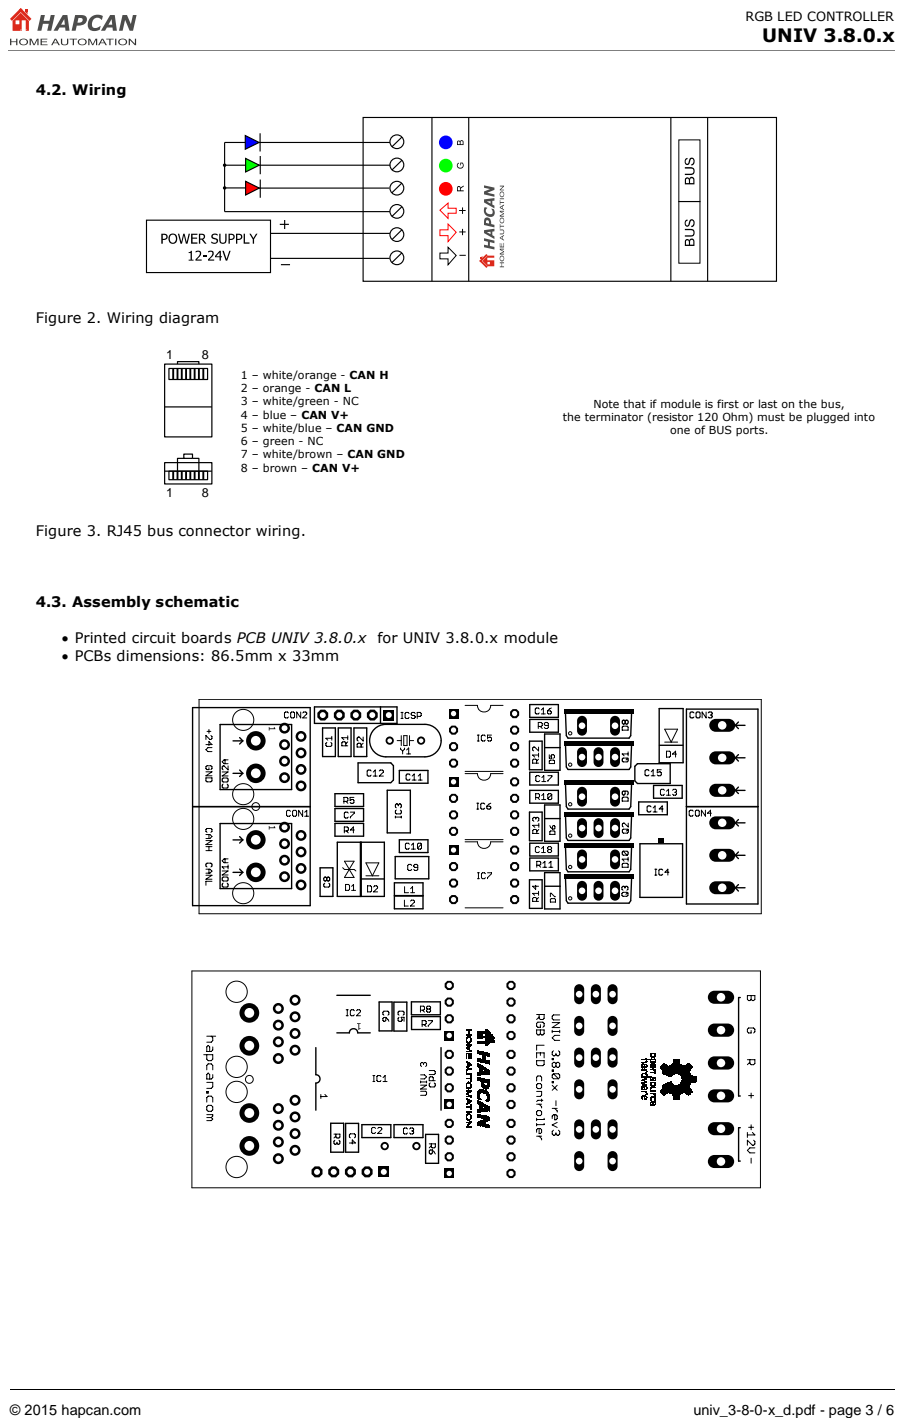
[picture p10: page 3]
4.2. Wiring; 4.3. Assembly schematic

Figure 2. Wiring diagram

1 – white/orange - CAN H
2 – orange - CAN L
3 – white/green - NC
4 – blue – CAN V+
5 – white/blue – CAN GND
6 – green - NC
7 – white/brown – CAN GND
8 – brown – CAN V+

Note that if module is first or last on the bus,
the terminator (resistor 120 Ohm) must be plugged into

one of BUS ports.

Figure 3. RJ45 bus connector wiring.

• Printed circuit boards PCB UNIV 3.8.0.x for UNIV 3.8.0.x module
• PCBs dimensions: 86.5mm x 33mm

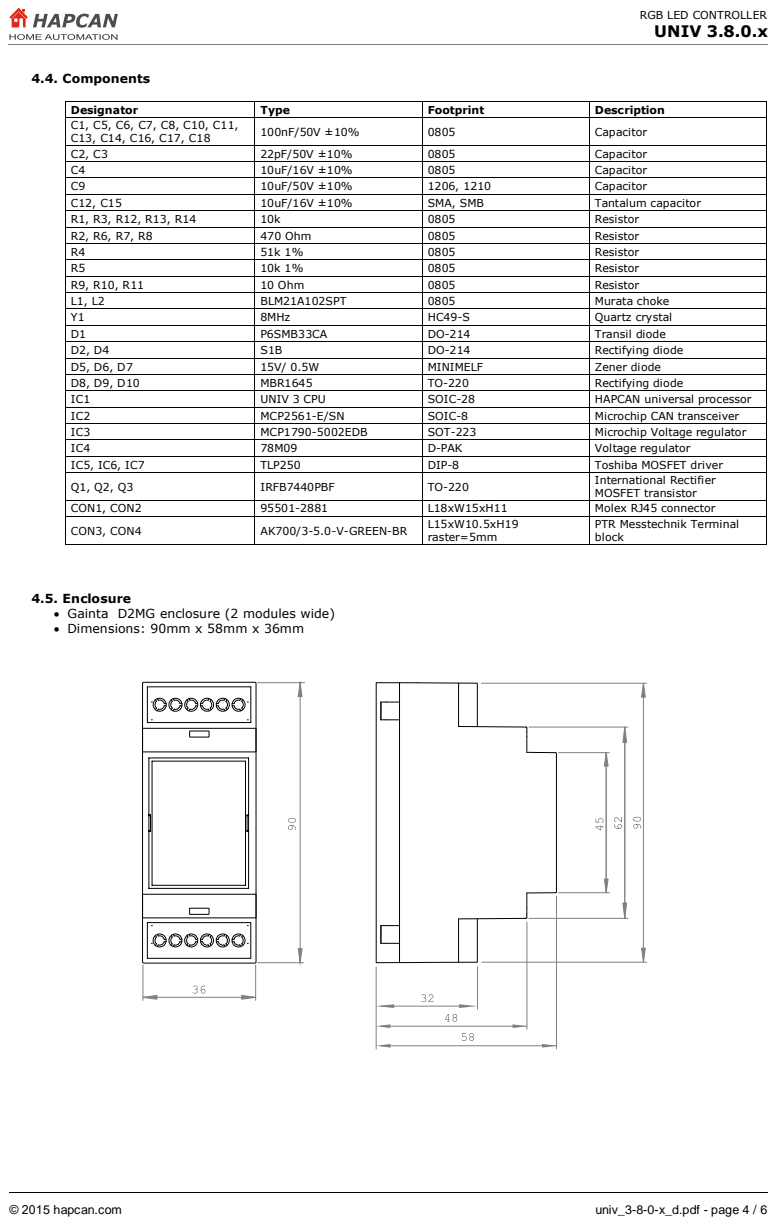
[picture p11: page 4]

Designator | Type | Footprint | Description
C1, C5, C6, C7, C8, C10, C11, C13, C14, C16, C17, C18 | 100nF/50V ±10% | 0805 | Capacitor

C2, C3 | 22pF/50V ±10% | 0805 | Capacitor
C4 | 10uF/16V ±10% | 0805 | Capacitor
C9 | 10uF/50V ±10% | 1206, 1210 | Capacitor
C12, C15 | 10uF/16V ±10% | SMA, SMB | Tantalum capacitor
R1, R3, R12, R13, R14 | 10k | 0805 | Resistor
R2, R6, R7, R8 | 470 Ohm | 0805 | Resistor
R4 | 51k 1% | 0805 | Resistor
R5 | 10k 1% | 0805 | Resistor
R9, R10, R11 | 10 Ohm | 0805 | Resistor
L1, L2 | BLM21A102SPT | 0805 | Murata choke
Y1 | 8MHz | HC49-S | Quartz crystal
D1 | P6SMB33CA | DO-214 | Transil diode
D2, D4 | S1B | DO-214 | Rectifying diode
D5, D6, D7 | 15V/ 0.5W | MINIMELF | Zener diode
D8, D9, D10 | MBR1645 | TO-220 | Rectifying diode
IC1 | UNIV 3 CPU | SOIC-28 | HAPCAN universal processor
IC2 | MCP2561-E/SN | SOIC-8 | Microchip CAN transceiver
IC3 | MCP1790-5002EDB | SOT-223 | Microchip Voltage regulator
IC4 | 78M09 | D-PAK | Voltage regulator
IC5, IC6, IC7 | TLP250 | DIP-8 | Toshiba MOSFET driver
Q1, Q2, Q3 | IRFB7440PBF | TO-220 | International Rectifier MOSFET transistor

CON1, CON2 | 95501-2881 | L18xW15xH11 | Molex RJ45 connector
CON3, CON4 | AK700/3-5.0-V-GREEN-BR | L15xW10.5xH19 raster=5mm | PTR Messtechnik Terminal block

4.5. Enclosure
• Gainta D2MG enclosure (2 modules wide)
• Dimensions: 90mm x 58mm x 36mm

### 4.6. Mechanical processing

Striped parts must be removed.

BODY | TERMINAL GUARDS

### 4.7. Labels

Editable labels version is available on hapcan.com site.

### 5. Commissioning

### 5.1. CPU voltage measurement

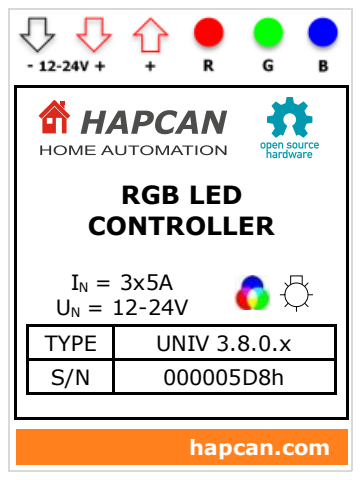
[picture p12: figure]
RGB LED CONTROLLER; TYPE; UNIV 3.8.0.x; hapcan.com

After verifying the correctness and quality of the soldering, the bus voltage should be connected while measuring the processor voltage. To do this, connect a voltmeter to pins 2 and 3 of the ICSP connector. Processor supply voltage should be about 5V.

Figure 3. CPU voltage measurement
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

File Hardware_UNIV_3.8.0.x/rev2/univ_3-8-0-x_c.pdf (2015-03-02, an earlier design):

## RGB LED CONTROLLER

# UNIV 3.8.0.x


© 2015 hapcan.com | univ_3-8-0-x_c.pdf - page 1 / 6

### 1. Features

- 3 channel LED controller
- Maximum load 120VA for each channel
- PWM (Pulse Width Modulation)
- Controller can generate any colour with required intensity of common anode RGB LED.
- Can work with:
- - RGB LEDs or three single colour LEDs (eg. LED strips, tapes, tubes etc.)
- - low voltage bulbs (classical and halogen 12-24V)
- Maximum LED supply voltage 12-24V
- Maximum LED current 5A for each channel
- Operation voltage 10-24V.
- Maximum current consumption from the bus 26mA.
- For DIN rail mounting.
- Dimensions 90x58x36 mm (2 mod)
- Operating of module depends on firmware uploaded into it.
- Schematic and PCB design can be downloaded from hapcan.com site

### 2. Application version

UNIV | 3 | . | 8 | . | 0 | . | x
firmware version
application version
application type (RGB LED controller) processor version
universal processor

### 3. Technical data

Bus side
Parameter | Symbol | Value | Unit
Power supply voltage | US | 10-24V | V
Maximum current consumption with all channels turn on | ISMAX | 26 | mA
Bus quiescent current | ISQ | 7 | mA
Bus connector type | 2x RJ45 connectors

RGB LED side
Parameter | Symbol | Value | Unit
Power supply voltage | UN | 12-24V | V
Maximum LED current for one channel | IN | 5 | A
Load Power for one channel | SN | 120 @24V | VA
Voltage regulating range | Uφ | 0 - UN | V
PWM frequency | f | 488 | Hz
Connector type | Terminal block 4mm²

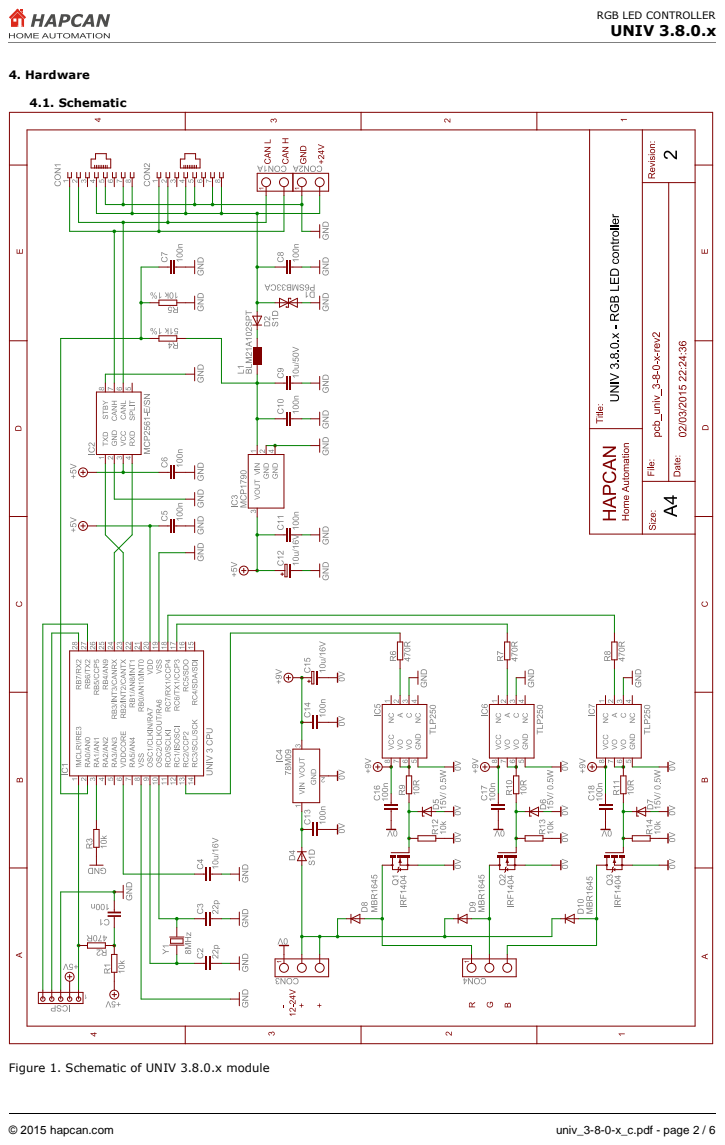
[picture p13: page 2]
4. Hardware; 4.1. Schematic

Figure 1. Schematic of UNIV 3.8.0.x module

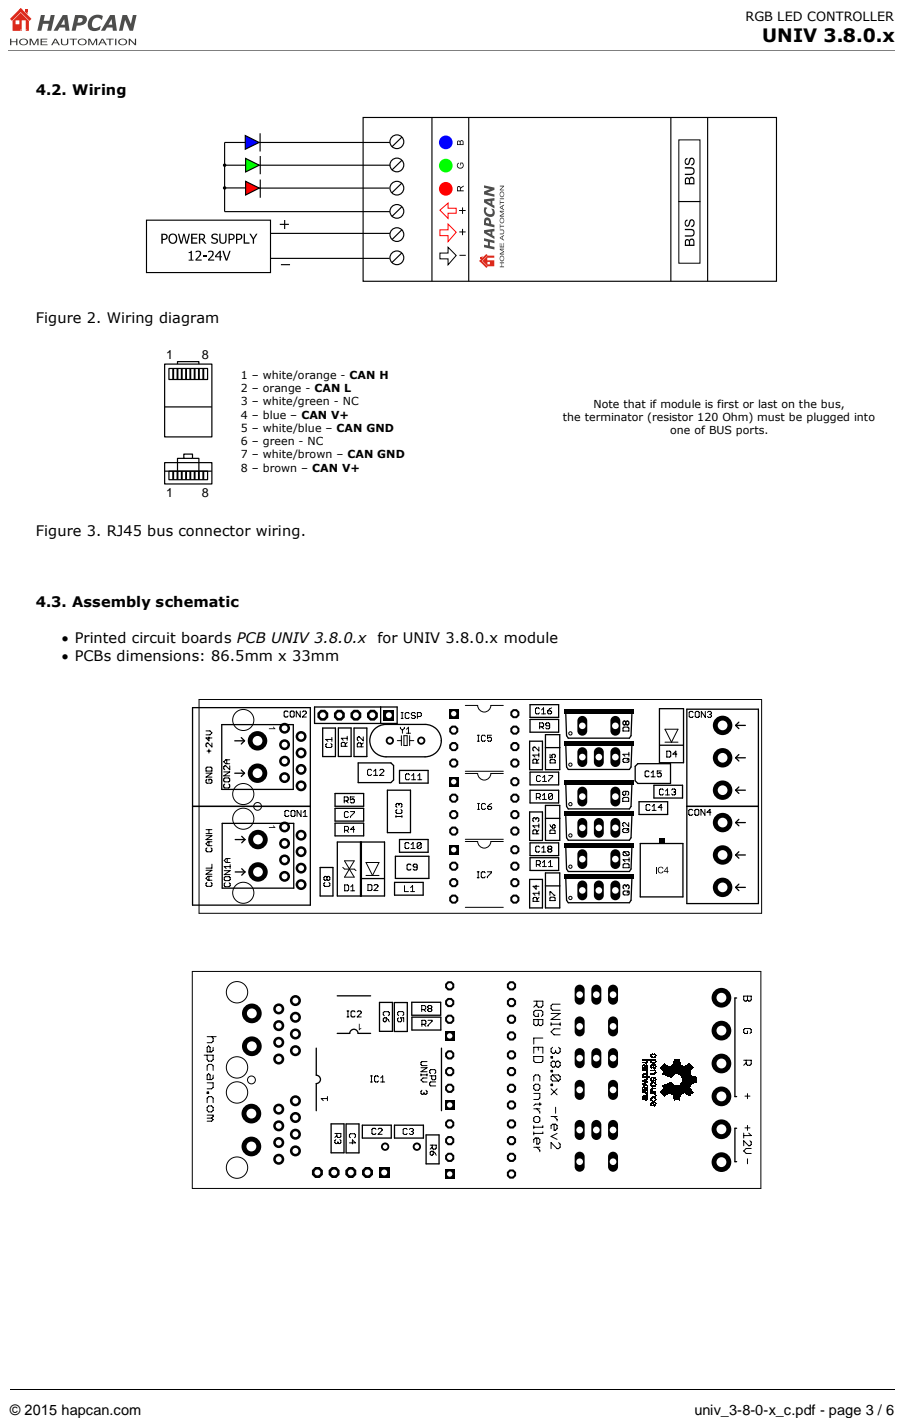
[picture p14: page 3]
4.2. Wiring; 4.3. Assembly schematic

Figure 2. Wiring diagram

1 – white/orange - CAN H
2 – orange - CAN L
3 – white/green - NC
4 – blue – CAN V+
5 – white/blue – CAN GND
6 – green - NC
7 – white/brown – CAN GND
8 – brown – CAN V+

Note that if module is first or last on the bus,
the terminator (resistor 120 Ohm) must be plugged into

one of BUS ports.

Figure 3. RJ45 bus connector wiring.

• Printed circuit boards PCB UNIV 3.8.0.x for UNIV 3.8.0.x module
• PCBs dimensions: 86.5mm x 33mm

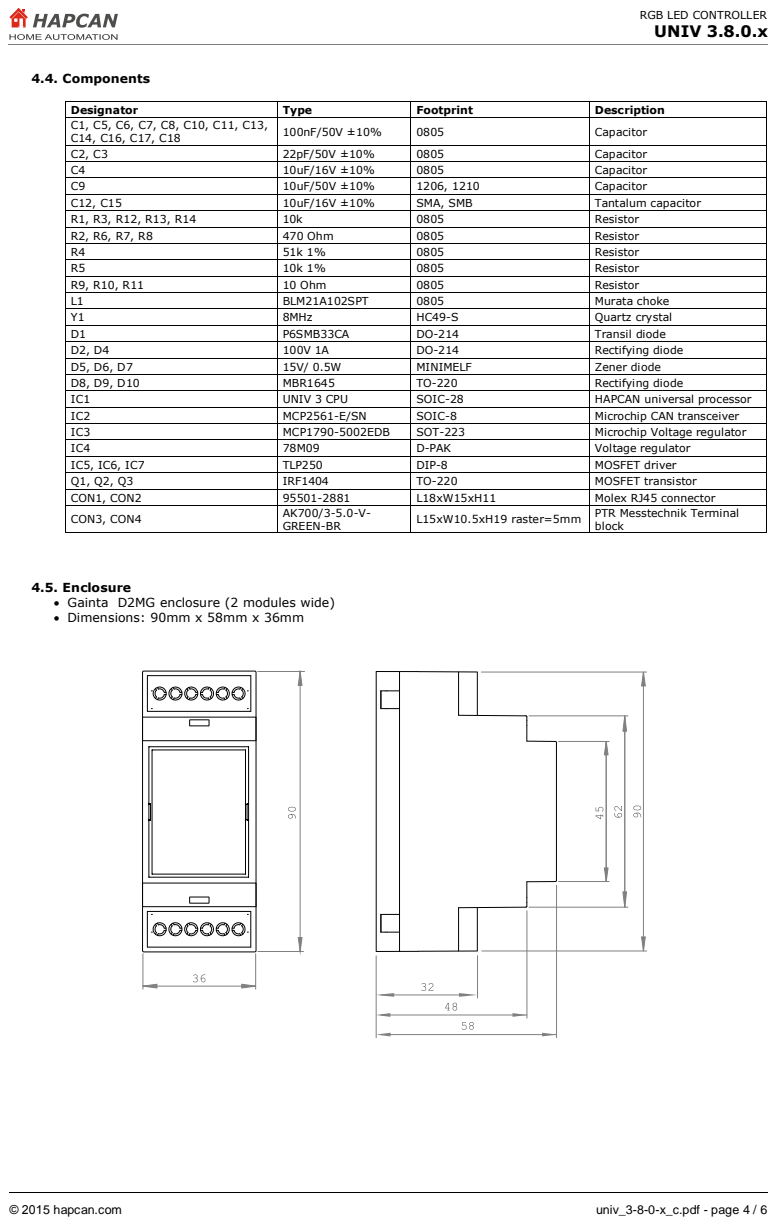
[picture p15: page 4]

Designator | Type | Footprint | Description
C1, C5, C6, C7, C8, C10, C11, C13, C14, C16, C17, C18 | 100nF/50V ±10% | 0805 | Capacitor

C2, C3 | 22pF/50V ±10% | 0805 | Capacitor
C4 | 10uF/16V ±10% | 0805 | Capacitor
C9 | 10uF/50V ±10% | 1206, 1210 | Capacitor
C12, C15 | 10uF/16V ±10% | SMA, SMB | Tantalum capacitor
R1, R3, R12, R13, R14 | 10k | 0805 | Resistor
R2, R6, R7, R8 | 470 Ohm | 0805 | Resistor
R4 | 51k 1% | 0805 | Resistor
R5 | 10k 1% | 0805 | Resistor
R9, R10, R11 | 10 Ohm | 0805 | Resistor
L1 | BLM21A102SPT | 0805 | Murata choke
Y1 | 8MHz | HC49-S | Quartz crystal
D1 | P6SMB33CA | DO-214 | Transil diode
D2, D4 | 100V 1A | DO-214 | Rectifying diode
D5, D6, D7 | 15V/ 0.5W | MINIMELF | Zener diode
D8, D9, D10 | MBR1645 | TO-220 | Rectifying diode
IC1 | UNIV 3 CPU | SOIC-28 | HAPCAN universal processor
IC2 | MCP2561-E/SN | SOIC-8 | Microchip CAN transceiver
IC3 | MCP1790-5002EDB | SOT-223 | Microchip Voltage regulator
IC4 | 78M09 | D-PAK | Voltage regulator
IC5, IC6, IC7 | TLP250 | DIP-8 | MOSFET driver
Q1, Q2, Q3 | IRF1404 | TO-220 | MOSFET transistor
CON1, CON2 | 95501-2881 | L18xW15xH11 | Molex RJ45 connector
CON3, CON4 | AK700/3-5.0-V-GREEN-BR | L15xW10.5xH19 raster=5mm | PTR Messtechnik Terminal block

4.5. Enclosure
• Gainta D2MG enclosure (2 modules wide)
• Dimensions: 90mm x 58mm x 36mm

### 4.7. Mechanical processing

Striped parts must be removed.

BODY | TERMINAL GUARDS

### 4.8. Labels

Editable labels version is available on hapcan.com site.

RGB LED
CONTROLLER

IN = 3x5A
UN = 12-24V
TYPE | UNIV 3.8.0.x
S/N | 000005D8h

hapcan.com

### 5. Commissioning

### 5.1. CPU voltage measurement

After verifying the correctness and quality of the soldering, the bus voltage should be connected while measuring the processor voltage. To do this, connect a voltmeter to pins 2 and 3 of the ICSP connector. Processor supply voltage should be about 5V.

Figure 3. CPU voltage measurement

### 5.2. Checking the CPU clock

Proper operation of the CPU can be checked by temporarily connecting the LED to pins 3 and 5 of the ICSP connector. When device is powered, the LED should light up four times in the sequence 1 second on - 1 second off
- 1 second on. The LED lights up only once for 50ms, if the processor is in programming mode.

Figure 4. Checking the CPU clock
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

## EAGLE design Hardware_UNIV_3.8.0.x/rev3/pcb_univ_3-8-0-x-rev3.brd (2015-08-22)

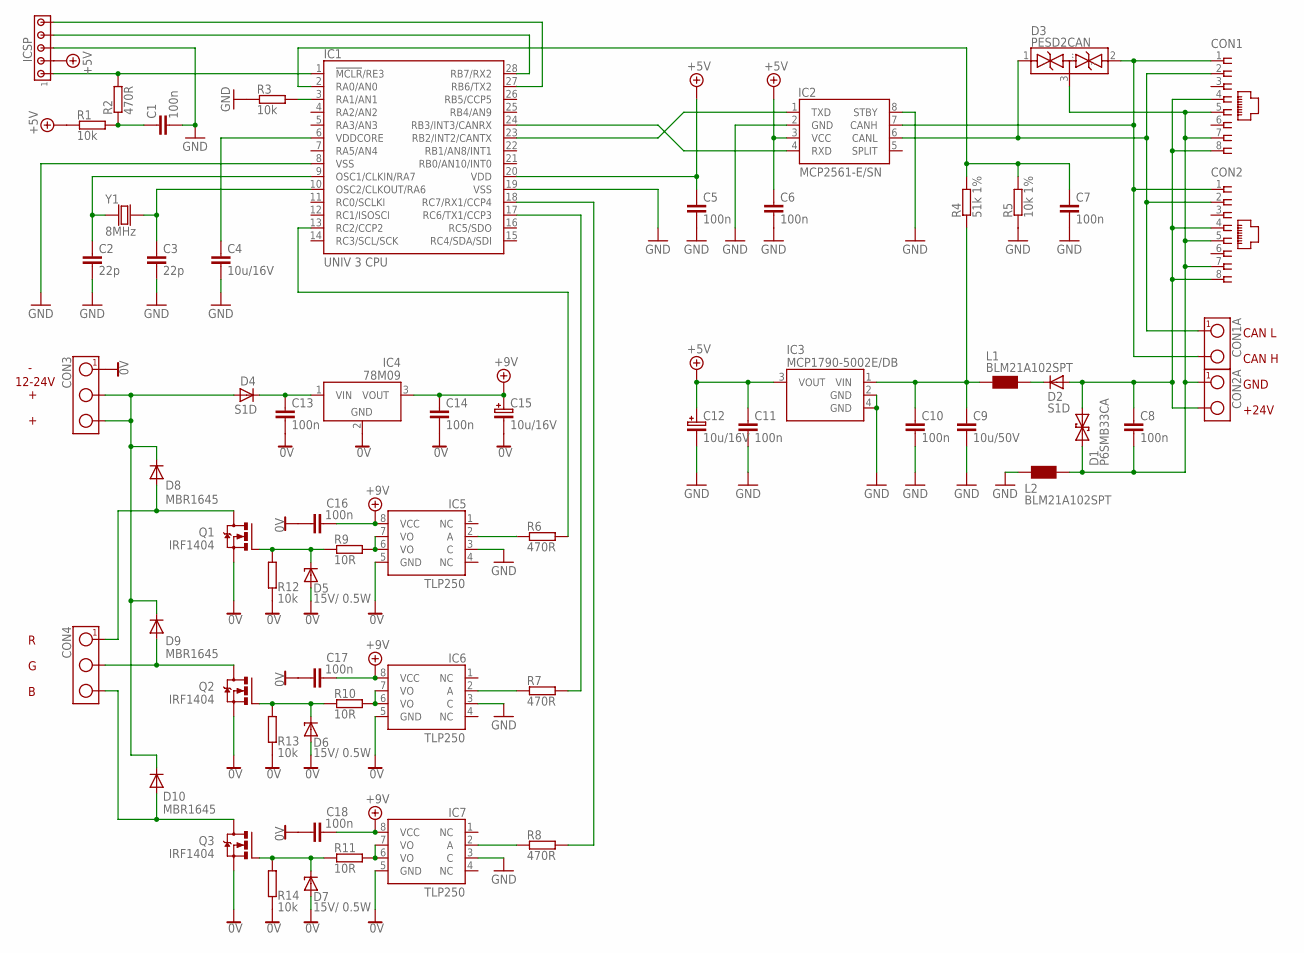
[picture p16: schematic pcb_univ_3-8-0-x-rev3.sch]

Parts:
C1, C5, C6, C7, C8, C10, C11, C13, C14, C16, C17, C18: 100n; 0805
C2, C3: 22p; 0805
C4: 10u/16V; 0805
C9: 10u/50V; 1210
C12, C15: 10u/16V; SMC_B
CON1, CON2: RJ45-SOCKET; RJ45-PCB-SOCKET
CON1A, CON2A: TERMINAL-2; ARK2-5X10,5MM
CON3, CON4: TERMINAL-3; ARK3-5X10.5MM
D1: P6SMB33CA; DO-214_TRANSIL2
D2, D4: S1D; DO-214
D3: PESD2CAN; SOT-23
D5, D6, D7: 15V/ 0.5W; SOD-80
D8, D9, D10: MBR1645; TO220V-2
IC1: UNIV 3 CPU; UNIV3CPU
IC2: MCP2561-E/SN; SO-08
IC3: MCP1790-5002E/DB; SOT-223
IC4: 78M09; TO-252
IC5, IC6, IC7: TLP250; DIL-08W
ICSP: HEADER5; SIP-5
L1, L2: BLM21A102SPT; 0805
Q1, Q2, Q3: IRF1404; TO220V
R1, R3, R12, R13, R14: 10k; 0805
R2, R6, R7, R8: 470R; 0805
R4: 51k 1%; 0805
R5: 10k 1%; 0805
R9, R10, R11: 10R; 0805
Y1: 8MHz; CRYSTAL-HC49V

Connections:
0V: C13.2, C14.2, C15.- (2), C16.1, C17.1, C18.1, CON3.1, D5.A, D6.A, D7.A, IC4.2 (GND), IC5.5 (GND), IC6.5 (GND), IC7.5 (GND), Q1.3 (S), Q2.3 (S), Q3.3 (S), R12.1, R13.1, R14.1
+5V: C5.1, C6.1, C11.1, C12.+ (1), IC1.20 (VDD), IC2.3 (VCC), IC3.3 (VOUT), ICSP.2, R1.1
+9V: C14.1, C15.+ (1), C16.2, C17.2, C18.2, IC4.3 (VOUT), IC5.8 (VCC), IC6.8 (VCC), IC7.8 (VCC)
GND: C1.2, C2.2, C3.2, C4.2, C5.2, C6.2, C7.2, C9.2, C10.2, C11.2, C12.- (2), IC1.8 (VSS), IC1.19 (VSS), IC2.2 (GND), IC2.8 (STBY), IC3.2 (GND), IC3.4 (GND), IC5.3 (C), IC6.3 (C), IC7.3 (C), ICSP.3, L2.1, R3.1, R5.1
unnamed: CON3.2, CON3.3, D4.A, D8.1 (C), D9.1 (C), D10.1 (C)
unnamed: IC1.24 (RB3/INT3/CANRX), IC2.4 (RXD)
unnamed: IC1.23 (RB2/INT2/CANTX), IC2.1 (TXD)
unnamed: CON1.1, CON1A.2, CON2.1, D3.2 (..), IC2.7 (CANH)
unnamed: IC5.6 (VO), IC5.7 (VO), R9.2
unnamed: IC6.6 (VO), IC6.7 (VO), R10.2
unnamed: C1.1, R1.2, R2.1
unnamed: IC1.1 (!MCLR!/RE3), ICSP.1, R2.2
unnamed: C8.1, CON1.4, CON1.8, CON2.4, CON2.8, CON2A.2, D1.C (2), D2.A
unnamed: IC1.28 (RB7/RX2), ICSP.4
unnamed: IC6.2 (A), R7.1
unnamed: IC1.3 (RA1/AN1), R3.2
unnamed: C13.1, D4.C, IC4.1 (VIN)
unnamed: IC1.27 (RB6/TX2), ICSP.5
unnamed: C3.1, IC1.10 (OSC2/CLKOUT/RA6), Y1.2
unnamed: C7.1, IC1.2 (RA0/AN0), R4.2, R5.2
unnamed: C9.1, C10.1, IC3.1 (VIN), L1.1, R4.1
unnamed: IC5.2 (A), R6.1
unnamed: IC1.13 (RC2/CCP2), R6.2
unnamed: IC1.17 (RC6/TX1/CCP3), R7.2
unnamed: IC1.18 (RC7/RX1/CCP4), R8.2
unnamed: C8.2, CON1.5, CON1.7, CON2.5, CON2.7, CON2A.1, D1.A (1), D3.3 (...), L2.2
unnamed: CON4.2, D9.3 (A), Q2.2 (D)
unnamed: D6.C, Q2.1 (G), R10.1, R13.2
unnamed: CON1.2, CON1A.1, CON2.2, D3.1 (.), IC2.6 (CANL)
unnamed: IC7.6 (VO), IC7.7 (VO), R11.2
unnamed: IC7.2 (A), R8.1
unnamed: D5.C, Q1.1 (G), R9.1, R12.2
unnamed: CON4.1, D8.3 (A), Q1.2 (D)
unnamed: CON4.3, D10.3 (A), Q3.2 (D)
unnamed: D7.C, Q3.1 (G), R11.1, R14.2
unnamed: C2.1, IC1.9 (OSC1/CLKIN/RA7), Y1.1
unnamed: C4.1, IC1.6 (VDDCORE)
unnamed: D2.C, L1.2

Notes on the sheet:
CAN L
CAN H
GND
+24V
12-24V

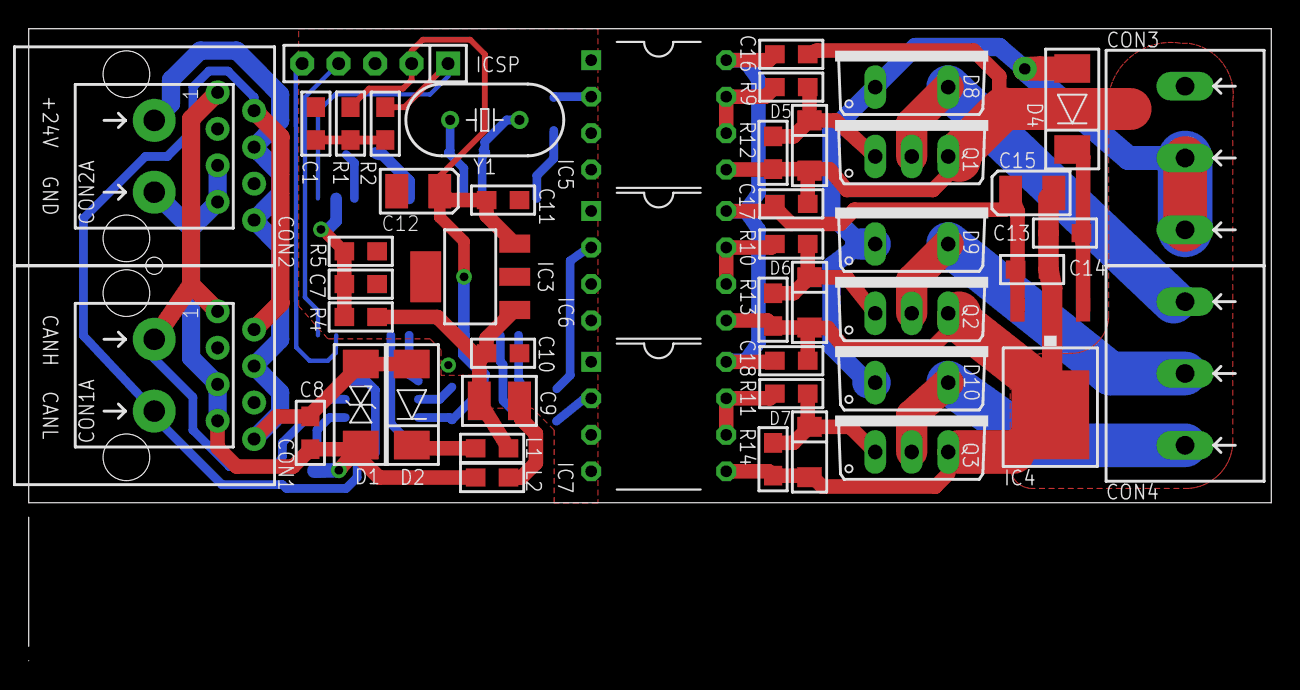
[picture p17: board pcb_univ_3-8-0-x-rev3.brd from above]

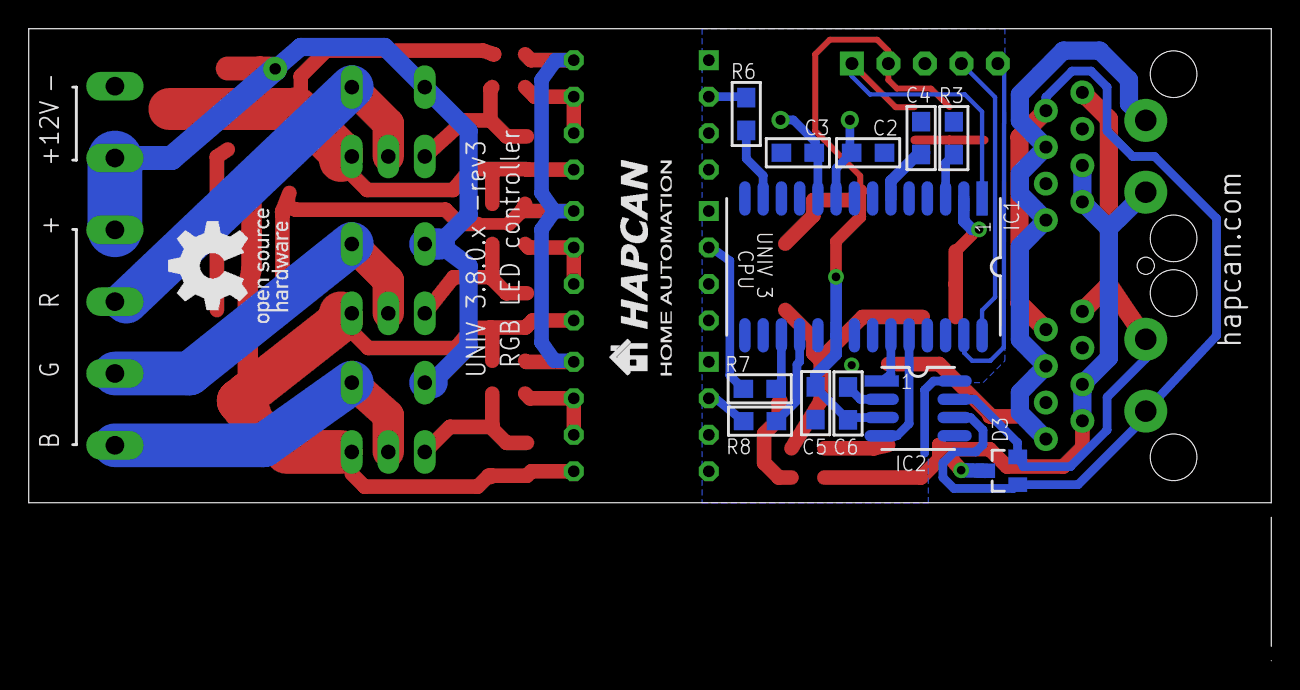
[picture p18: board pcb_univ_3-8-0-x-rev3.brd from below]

Board: 2 copper layers, 86.5 x 33.0 mm, 62 parts (12 on the bottom side), 38 nets.

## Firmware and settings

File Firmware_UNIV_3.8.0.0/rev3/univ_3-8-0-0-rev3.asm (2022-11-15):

;==============================================================================
;   MIT License
;
;   Copyright (c) 2022 HAPCAN Home Automation Project (http://hapcan.com)
;
;   Permission is hereby granted, free of charge, to any person obtaining a copy
;   of this software and associated documentation files (the "Software"), to deal
;   in the Software without restriction, including without limitation the rights
;   to use, copy, modify, merge, publish, distribute, sublicense, and/or sell
;   copies of the Software, and to permit persons to whom the Software is
;   furnished to do so, subject to the following conditions:
;
;   The above copyright notice and this permission notice shall be included in all
;   copies or substantial portions of the Software.
;
;   THE SOFTWARE IS PROVIDED "AS IS", WITHOUT WARRANTY OF ANY KIND, EXPRESS OR
;   IMPLIED, INCLUDING BUT NOT LIMITED TO THE WARRANTIES OF MERCHANTABILITY,
;   FITNESS FOR A PARTICULAR PURPOSE AND NONINFRINGEMENT. IN NO EVENT SHALL THE
;   AUTHORS OR COPYRIGHT HOLDERS BE LIABLE FOR ANY CLAIM, DAMAGES OR OTHER
;   LIABILITY, WHETHER IN AN ACTION OF CONTRACT, TORT OR OTHERWISE, ARISING FROM,
;   OUT OF OR IN CONNECTION WITH THE SOFTWARE OR THE USE OR OTHER DEALINGS IN THE
;   SOFTWARE.
;==============================================================================
;   Filename:              univ_3-8-0-0.asm
;   Associated diagram:    univ_3-8-0-x.sch
;   Author:                Jacek Siwilo                          
;   Note:                  RGB LED Controller 
;   !!!Notice that PWM controlling of RGB LEDs is patented by Philips!!!
;==============================================================================
;   Revision History
;   Rev:  Date:     Details:
;   0     01.2014   Original version
;   1     11.2015   Updated with "univ3-routines-rev4.inc"
;   2     12.2016   Updated with "univ3-routines-rev6.inc"
;   3     11.2022   Updated with "univ3-routines-rev9.inc"
;==============================================================================
;===  FIRMWARE DEFINITIONS  =================================================== 
;==============================================================================
    #define    ATYPE    .8                            ;application type [0-255]
    #define    AVERS    .0                         ;application version [0-255]
    #define    FVERS    .0                            ;firmware version [0-255]

    #define    FREV     .3                         ;firmware revision [0-65536]
;==============================================================================
;===  NEEDED FILES  ===========================================================
;==============================================================================
    LIST P=18F26K80                              ;directive to define processor
    #include <P18F26K80.INC>           ;processor specific variable definitions
    #include "univ_3-8-0-0-rev3.inc"                         ;project variables
INCLUDEDFILES   code  
    #include "univ3-routines-rev9.inc"                     ;UNIV 3 CPU routines
;==============================================================================
;===  FIRMWARE CHECKSUM  ======================================================
;==============================================================================
FIRMCHKSM   code    0x001000
    DB      0x60, 0x23, 0x70, 0xFF, 0xFF, 0xFF, 0xFF, 0xFF            
;==============================================================================
;===  FIRMWARE ID  ============================================================
;==============================================================================
FIRMID      code    0x001010
    DB      0x30, 0x00, 0x03,ATYPE,AVERS,FVERS,FREV>>8,FREV
;            |     |     |     |     |     |     |_____|_____ firmware revision
;            |     |     |     |     |     |__________________ firmware version
;            |     |     |     |     |_____________________ application version
;            |     |     |     |______________________________ application type
;            |     |     |________________________________ hardware version '3'
;            |_____|______________________________________ hardware type 'UNIV'
;==============================================================================
;===  MOVED VECTORS  ==========================================================
;==============================================================================
;PROGRAM RESET VECTOR
FIRMRESET   code    0x1020
        goto    Main
;PROGRAM HIGH PRIORITY INTERRUPT VECTOR
FIRMHIGHINT code    0x1030
        call    HighInterrupt
        retfie
;PROGRAM LOW PRIORITY INTERRUPT VECTOR
FIRMLOWINT  code    0x1040
        call    LowInterrupt
        retfie

;==============================================================================
;===  FIRMWARE STARTS  ========================================================
;==============================================================================
FIRMSTART   code    0x001050
;------------------------------------------------------------------------------
;---  LOW PRIORITY INTERRUPT  -------------------------------------------------
;------------------------------------------------------------------------------
LowInterrupt
        movff   STATUS,STATUS_LOW           ;save STATUS register
        movff   WREG,WREG_LOW               ;save working register
        movff   BSR,BSR_LOW                 ;save BSR register
        movff   FSR0L,FSR0L_LOW             ;save other registers used in low int
        movff   FSR0H,FSR0H_LOW
        movff   FSR1L,FSR1L_LOW
        movff   FSR1H,FSR1H_LOW

    ;main firmware ready flag
        banksel FIRMREADY
        btfss   FIRMREADY,0
        bra     ExitLowInterrupt            ;main firmware is not ready yet
    ;CAN buffer
        banksel CANFULL
        btfsc   CANFULL,0                   ;check if CAN received anything
        call    CANInterrupt                ;proceed with CAN interrupt

ExitLowInterrupt
        movff   BSR_LOW,BSR                 ;restore BSR register
        movff   WREG_LOW,WREG               ;restore working register
        movff   STATUS_LOW,STATUS           ;restore STATUS register
        movff   FSR0L_LOW,FSR0L             ;restore other registers used in low int
        movff   FSR0H_LOW,FSR0H
        movff   FSR1L_LOW,FSR1L
        movff   FSR1H_LOW,FSR1H
    return
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

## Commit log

2014-01-19 hardware revision 1
    [pcb_univ_3-8-0-x-rev1.brd, pcb_univ_3-8-0-x-rev1.sch]
2014-01-24 firmware revision 0
    [univ_3-8-0-0-rev0-memory.xlsx]
2015-03-02 hardware revision 2
    [pcb_univ_3-8-0-x-rev2.brd, pcb_univ_3-8-0-x-rev2.sch]
2015-08-22 hardware revision 3
    [pcb_univ_3-8-0-x-rev1.brd, pcb_univ_3-8-0-x-rev1.sch, pcb_univ_3-8-0-x-rev2.brd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]
2015-08-22 Revert "hardware revision 3"
    This reverts commit d9c47e6ec6357fc9da491421f110c58338fb49fe.
    [pcb_univ_3-8-0-x-rev1.brd, pcb_univ_3-8-0-x-rev1.sch, pcb_univ_3-8-0-x-rev2.brd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]
2015-11-08 firmware UNIV 3.8.0.0 revision 1
    [univ_3-8-0-0-rev1-memory.xlsx, univ_3-8-0-0-rev1-phase_delay_step.xlsx]
2016-12-30 firmware UNIV 3.8.0.0 revision 2
    [univ_3-8-0-0-rev2-memory.xlsx, univ_3-8-0-0-rev2-phase_delay_step.xlsx]
2022-11-15 firmware UNIV 3.8.0.0 revision 3
    [univ_3-8-0-0-rev3-memory.xlsx, univ_3-8-0-0-rev3-phase_delay_step.xlsx]

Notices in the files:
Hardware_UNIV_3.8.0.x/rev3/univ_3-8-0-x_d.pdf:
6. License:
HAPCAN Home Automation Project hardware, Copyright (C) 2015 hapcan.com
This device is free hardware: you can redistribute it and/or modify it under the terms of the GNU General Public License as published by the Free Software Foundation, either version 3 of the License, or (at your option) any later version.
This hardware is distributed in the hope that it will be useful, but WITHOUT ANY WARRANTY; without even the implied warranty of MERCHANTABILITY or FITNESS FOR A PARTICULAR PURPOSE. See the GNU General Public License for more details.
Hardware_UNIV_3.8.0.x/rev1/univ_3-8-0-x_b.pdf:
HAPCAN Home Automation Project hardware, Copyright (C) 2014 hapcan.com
